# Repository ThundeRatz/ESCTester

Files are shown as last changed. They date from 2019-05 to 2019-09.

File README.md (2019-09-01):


# ESC Tester

Repositório do projeto de uma ESC Tester, feito para o processo seletivo de 2019 da equipe de robótica ThundeRatz.

# Placa

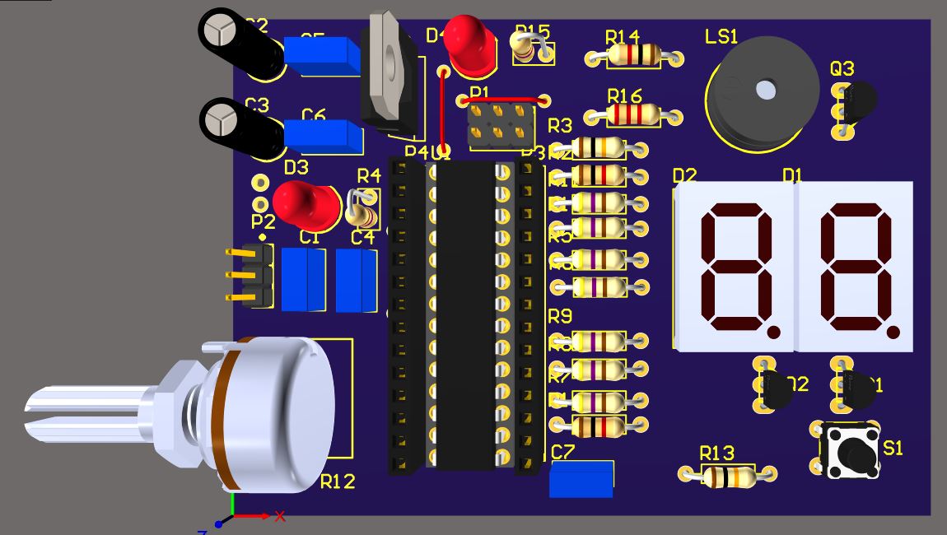
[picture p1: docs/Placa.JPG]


A placa possui:
- dois displays 7 segmentos para mostrar a porcentagem da ppm mandada para a ESC e também o modo escolhido;
- botão para a escolha do modo, para iniciar o sinal caso seja segurado e o término do sinal para finalizar caso esteja rodando;
- potenciômetro para escolher o valor máximo do sinal mandado para a ESC;
- buzzer para indicar o início do sinal;
- regulador 3V3 para regular o BEC da ESC ou a alimentação externa de 5V;
- pinos de gravação no modelo ISP6.

# Programa

O programa foi feito em AVR para o microcontrolador Atmega8, da Atmel.

**Modos**

A ESC_Tester possui 5 modos de operação, para ESCs unidirecionais e ESCs bidirecionais:

1- Unidirecional variável: A PPM varia entre o valor mínimo da PPM até o valor máximo escolhido no potenciômetro;

2- Unidirecional fixo: A PPM aumenta do valor mínimo até o máximo e se mantém nesse valor;

3- Bidirecional variável em dois sentidos: A PPM se inicia simulando o stick do controle centrado, variando entre o valor escolhido no potenciômetro nos dois sentidos do motor;

4- Bidirecional variável em apenas um sentido: Semelhante ao modo 1, mas para ESCs bidirecionais;

5- Bidirecional fixo: Semelhante ao modo 2, mas para ESCs bidirecionais.

**Máquina de Estados**

Ele é baseado numa máquina de estados que segue o seguinte diagrama:



Estados:
- INIT: Ele inicializa as portas, o ADC e a PWM;
- CHOOSE: Esse estado mostra a porcentagem que o potenciômetro está, lido por ADC, e mostra nos displays de 7 segmentos, ligando um de cada vez em um intervalo entre eles imperceptível ao olho. Esse estado espera o botão ser apertado;
- WAIT_BUTTON: Nesse estado, ele verifica se o botão está sendo apertado ou foi pressionado rapidamente. Caso tenha sido apenas pressionado, há a mudança do modo selecionado, se estiver pressionado,a PPM se inicia, passando por uma rotina de calibração da ESC;
- PPM: Esse estado envia a PPM para a ESC, variando de acordo com o modo selecionado. Ao apertar o botão novamente, a ESC_Tester para de enviar o sinal PPM e volta ao estado de seleção.

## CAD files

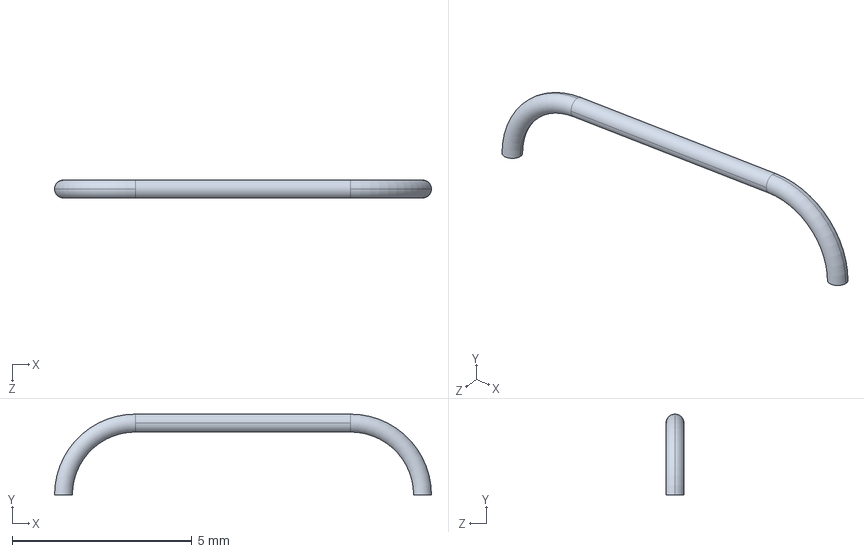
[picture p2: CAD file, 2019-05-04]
ESC_Tester/jumper1.STEP
10.5 x 2.25 x 0.5 mm

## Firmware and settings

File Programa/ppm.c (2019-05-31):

/**
 * @file    ppm.h
 * @brief   ThundeRatz's ESC_Tester Project Firmware.
 *
 * @author Gustavo Hama <gustavo.hama@thunderatz.org>
 * @author Daniel Nery <daniel.nery@thunderatz.org>
 *
 * @date 04/2018
 */

#include <avr/io.h>
#include <stdbool.h>
#include <util/delay.h>

#include "led.h"
#include "ppm.h"
#include "timer.h"

#define PPM_CALIB_INTERVAL_MS 3000
#define PPM_CALIB_POST_TIME_MS 6000

/*****************************************
 * Public Variables
 *****************************************/

uint16_t ppm_reset[] = {
    0,
    PPM_MIN,
    PPM_MIN,
    PPM_MID,
    PPM_MID,
    PPM_MID,
};

/*****************************************
 * Public Functions Bodies Definitions
 *****************************************/

void ppm_init() {
    DDRB |= (1 << PB2);

    // Inicializacao da fast PWM, período regulado pelo ICR1
    TCCR1A = (1 << WGM11);
    TCCR1B = (1 << WGM12) | (1 << WGM13) | (1 << CS11);

    // Habilita
    TCCR1A |= (1 << COM1B1);

    ICR1 = TIM_PPM_PERIOD;  // Para a frequencia ser 50 Hz

}

void calibrate(ppm_mode_t mode) {
    ppm_init();

    if ((mode == VAR_UNI) | (mode == FIXO_UNI)) {  // Calibrar
        PPM_REG = PPM_MAX;
        _delay_ms(PPM_CALIB_INTERVAL_MS);
        PPM_REG = PPM_MIN;
        _delay_ms(PPM_CALIB_INTERVAL_MS);
    }

    if ((mode == VAR_DOIS_BI) | (mode == VAR_UM_BI) | (mode == FIXO_BI)) {  // Calibrar para bidirecional
        PPM_REG = PPM_MAX;
        _delay_ms(PPM_CALIB_INTERVAL_MS);
        PPM_REG = PPM_MIN;
        _delay_ms(PPM_CALIB_INTERVAL_MS);
        PPM_REG = PPM_MID;
        _delay_ms(PPM_CALIB_INTERVAL_MS);
    }
    // Espera a calibracao da ESC
    _delay_ms(PPM_CALIB_POST_TIME_MS);
}

void ppm(uint8_t adc, ppm_mode_t mode) {
    static bool subida = true;

    uint16_t ppm_max_uni = PPM_MIN + 10 * adc;  // OCR1B vai ate 20000, entao a ppm deve ir de 1000 a 2000.
    uint16_t ppm_max_rev = PPM_MID + 5 * adc;
    uint16_t ppm_min_rev = PPM_MID - 5 * adc;

    if (subida) {
        led_on();
    } else {
        led_off();
    }

    switch (mode) {
        case NO_MODE: {
            PPM_REG = 0;
            break;
        }

        case VAR_UNI: {  // variavel, unidirecional
            if (PPM_REG >= ppm_max_uni) {
                subida = false;
            } else if (PPM_REG <= PPM_MIN) {
                subida = true;
            }

            if (subida) {
                PPM_REG++;
            } else {
                PPM_REG--;
            }

            break;
        }

        case FIXO_UNI: {  // fixo, unidirecional
            if (PPM_REG < ppm_max_uni) {
                PPM_REG++;
            } else if (PPM_REG > ppm_max_uni){
                PPM_REG--;
            }

            break;
        }

        case VAR_DOIS_BI: {  // variavel, dois sentidos, bidirecional
            if (PPM_REG >= ppm_max_rev) {
                subida = false;
            } else if (PPM_REG <= ppm_min_rev) {
                subida = true;
            }

            if (subida) {
                PPM_REG++;
            } else {
                PPM_REG--;
            }

            break;
        }

        case VAR_UM_BI: {  // variavel, um sentido, bidirecional
            if (PPM_REG >= ppm_max_rev) {
                subida = false;
            } else if (PPM_REG <= PPM_MID) {
                subida = true;
            }

            if (subida) {
                PPM_REG++;
            } else {
                PPM_REG--;
            }

            break;
        }

        case FIXO_BI: {  // fixo, bidirecional
            if (PPM_REG < ppm_max_rev) {
                PPM_REG++;
            } else if (PPM_REG > ppm_max_rev) {
                PPM_REG--;
            }

            break;
        }
    }

    _delay_ms(15);
}

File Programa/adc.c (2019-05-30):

/**
 * @file    adc.c
 * @brief   ThundeRatz's ESC_Tester Project Firmware.
 *
 * @author Gustavo Hama <gustavo.hama@thunderatz.org>
 * @author Daniel Nery <daniel.nery@thunderatz.org>
 *
 * @date 04/2018
 */

#include <avr/io.h>

#include "adc.h"

/*****************************************
 * Public Functions Bodies Definitions
 *****************************************/

void adc_init(void) {
    ADMUX |= (1 << REFS0);
    ADCSRA |= (1 << ADEN) | (1 << ADPS2) | (1 << ADPS1) | (1 << ADPS0);
}

uint8_t get_adc(void) {
    uint8_t measure;

    // Inicia a conversao
    ADCSRA |= (1 << ADSC);

    // Ate terminar a conversao
    while (ADCSRA & (1 << ADSC))
        ;

    measure = (100 * ADC) >> 10;  // Porcentagem 100 * ADC / 1024 (2 ^ 10)

    return measure;
}

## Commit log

2019-03-19 :tada: Initial commit
    [ESC_Tester.PrjPcb, ESC_Tester_PCB.PcbDoc, ESC_Tester_SCH.SchDoc]
2019-04-04 Correção buzzer e saída de PPM
2019-04-10 Organiza e termina a maquina de estados
2019-04-10 Fix details on ppm
    [ppm.c]
2019-04-10 Cor top da placa
    [ESC_Tester_PCB.PcbDoc]
2019-04-12 Para bixos
    [ESC_Tester.PrjPcb, ESC_Tester_SCH.SchDoc]
2019-04-17 New rules
    [ESC_Tester_PCB.PcbDoc]
2019-05-04 Add jumpers 3D model
    [ESC_Tester.PrjPcb, ESC_Tester_PCB.PcbDoc, jumper1.STEP]
2019-05-30 Code Fixes
    - Build files on build folder
    - Remove unnecessary division
    - Fix some conditions
    [adc.c, ppm.c]
2019-05-31 Fix code
    - Remove wrong comment
    - Fix logic at mode 5
    [ppm.c]
2019-05-31 Schematic change
    Description text in english
    [ESC_Tester_SCH.SchDoc]
